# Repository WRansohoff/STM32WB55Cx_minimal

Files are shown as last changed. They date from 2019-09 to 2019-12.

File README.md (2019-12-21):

# STM32WB55 Example Board

**NOTE: I haven't had a chance to test this board much yet, so if you stumble across this, please wait a few weeks before trying to make one!** I'll update the repository with full gerber files and more information once I've checked that the radio/antenna/etc. work. It's my first RF design, so they might not.

I have received a first revision of the boards and verified that the microcontrollers can be programmed with a simple 'blinking LED' application, but I haven't tested any of the advanced peripherals such as USB or Bluetooth. Also, I think that I accidentally reversed the power pins on the USB connector footprint, so it's a good thing that I included a reverse polarity protection diode! That will be fixed shortly, but for now it is a reminder not to order one of these boards yet :)

I've been trying to do a better job of documenting the board designs that I make, so hopefully this can eventually grow into a useful reference design. In the meantime, sorry for the inconvenience and stay tuned.

# Board Renders

I tried to design this so that it could be soldered by hand if you don't have access to PCA services or a reflow station, but the small 0402 parts take a steady hand:

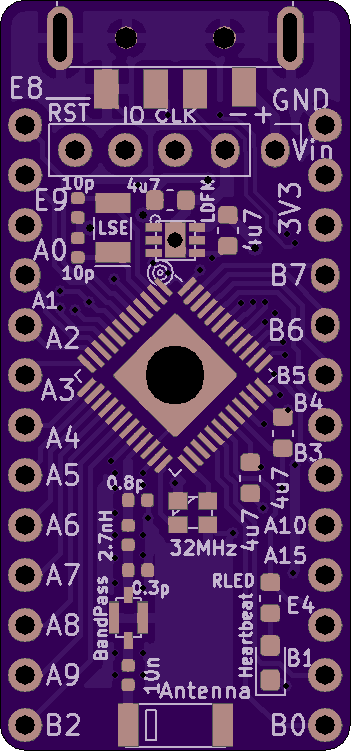
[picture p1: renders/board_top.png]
Board Top

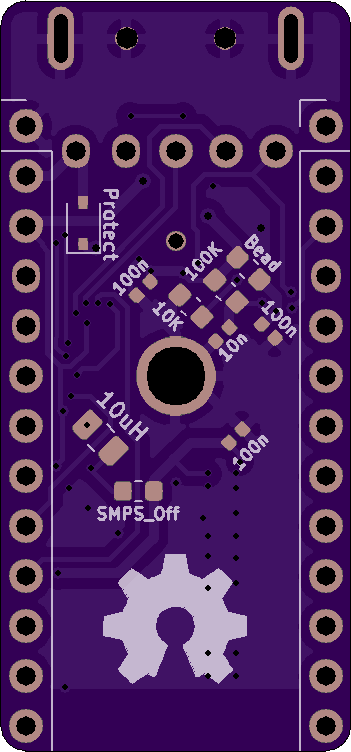
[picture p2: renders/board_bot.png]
Board Bottom


# Future Work

* Obviously, I need to write suitable firmwares to test the radio systems, USB communication, internal switching power supply, etc.

* Instead of using a separate bandpass filter and impedance-matching network, it might be easier to use an integrated filter chip which ST designed for these microcontrollers; part #MLPF-WB55-01E3. It only costs about $0.30, and it seems less error-prone than blindly using the pi filter values from the reference schematics.

* Adding an input button might be a good idea, to extend the range of potential applications.

* I should add a switch or jumper connected to the `BOOT0` pin, because it looks like it is only possible to change or update the co-processor's radio firmware in DFU mode. Fortunately, with the current design, you can remove the 10K resistor on the bottom of the board and solder a jumper between the `BOOT0` side of its pad and the `VDD` side of the 100K resistor which is right next to it. But that's not a good solution.

* Maybe I should move the `SWDIO`, `SWCLK`, and `NRST` pins to the two headers on either side of the board; it's unwieldy to have pin headers overhanging the USB plug.

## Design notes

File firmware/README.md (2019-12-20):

# Test STM32WB55 Firmwares

This directory contains test firmwares for the board design that this repository demonstrates.

I haven't gotten any of the RF stuff working yet, so the only firmware right now is a simple 'blinking LED' program which toggles the on-board LED connected to PE4 to verify that the chip can be programmed, boot, and run an application.

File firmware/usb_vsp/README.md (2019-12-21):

# Overview

Test 'virtual COM port' application, which uses the USB peripheral to set up a virtual serial connection similar to plugging a USB/UART converter into one of the chip's UART peripherals.

I would like to use the example in ST's `STM32Cube` firmware package to test my STM32WB55 USB dongles' 2.4GHz radios, but when I try to use the `BLE_TransparentModeVCP` project with any hardware (including the official 'Nucleo' USB dongle), it fails to enumerate as a USB device on both Windows 10 and Linux machines. It encounters the same error in both cases ('device fails to respond to published address'), and neigher the 'old' nor 'new' style `usbcore` enumerations work on Linux. I started trying to debug the issue and discovered that, at least with STM32 chips, these errors are often caused when a firmware fails to disable the USB peripheral's "VBUS sensing" option. But digging through the endlessly-nesting STM32Cube example code is *way* too tedious and annoying for a fun hobby project. I'm just not going to do it.

I've been meaning to learn about the STM32 USB peripheral anyways though, so I see this as an opportunity rather than a problem. And in fairness to ST, their `BLE_TransparentMode` project for the 'Nucleo' mainboard works very well; the `ST-Link` VCP functionality is excellent. Sadly, the implementation that they use in v1.3 of the STM32WB Cube package does not seem to work, even with their own hardware.

NB: this is a fairly new product line and these sorts of difficulties are not unique to ST, whose products I generally like and admire. It is not unusual or unreasonable to see this sort of "did they even test this?" error, because it is not trivial for a company to test every configuration of every example with every board that they ostensibly support. Plus, as with most other embedded products, you can't expect things to work "out-of-the-box", and you can't expect technical support unless you make large ongoing purchases directly from the company. C'est la vie! `¯\_(ツ)_/¯`

# Current Status

Currently, this test firmware is a non-functional work-in-progress.

I've only started to set up the clocks for the USB peripheral; there is a built-in 48MHz internal RC oscillator, and it looks like you're supposed to use the 'clock recovery system' peripheral to synchronize it with the USB start-of-frame packets which are sent at a 1KHz frequency. I think it's also okay to use a more precise 48MHz signal, such as one derived from an external crystal using the PLL, but the HSI48 oscillator combined with the CRS peripheral looks like the simplest option to start with.

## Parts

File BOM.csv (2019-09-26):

Part ID | Part type | Part size | Part value | Example Digikey Item | Cost (qty: x) | Comment
AE1 | Antenna | Custom | Unictron H2U262GKBA0100 | https://www.digikey.com/short/p2h8zn | $0.64 | Trace antennas are cheaper, but this seemed like a less failure-prone option for a first attempt.
C1 | Capacitor | 0402 | 0.8 pF | https://www.digikey.com/short/p2hrp7 | $0.15 | 50Ω matching filter capacitor. I used the values from ST's evaluation board, figuring they'd probably be fairly close. Ideal values will vary based on your board stackup. Prefer high-quality ceramic capacitors (C0G/NP0)
C2 | Capacitor | 0402 | 0.3 pF | https://www.digikey.com/short/p2hrjw | $0.19 | Another 50Ω matching filter capacitor.
C3, C4, C5 | Capacitor | 0402 | 100 nF | https://www.digikey.com/short/p2hrz2 | $0.30 | Power supply decoupling capacitors. Prefer X5/X7 ceramic capacitors.
C6, C7 | Capacitor | 0603 | 4.7 μF | https://www.digikey.com/short/p2hdqt | $0.34 | SMPS decoupling capacitors for the built-in switching power supply. Prefer X5/X7 ceramic capacitors.
C8, C9 | Capacitor | 0402 | 10 pF | https://www.digikey.com/short/p2hrhj | $0.20 | Filtering capacitors for the 32.768KHz 'Low-Speed External' crystal oscillator. Prefer high-quality C0G/NP0 ceramic capacitors.
C10, C11 | Capacitor | 0603 | 4.7 μF | https://www.digikey.com/short/p2hdqt | $0.34 | Decoupling capacitors for the 3.3V voltage regulator. Prefer X5/X7 ceramic capacitors.
C12 | Capacitor | 0402 | 10 nF | https://www.digikey.com/short/p2hr54 | $0.10 | Filtering capacitor that sits between the 2.45GHz bandpass filter and the antenna. Prefer X7 ceramic capacitor.
C13 | Capacitor | 0402 | 10 nF | https://www.digikey.com/short/p2hr54 | $0.10 | Decoupling capacitor for the reset line.
D1 | Schottky Diode | SOD-323 | 20-40V, 0.5-2A | https://www.digikey.com/short/p2hd37 | $0.31 | Schottky diode to protect against reverse polarity.
D2 | LED | 0603 | Your favorite color | https://www.digikey.com/short/p2hdpf | $0.14 | LED indicator connected to pin E4.
FL1 | Filter | 0805 | 2.45GHz bandpass | https://www.digikey.com/short/p2hndq | $0.24 | Bandpass filter which goes between the 50Ω impedance matching network and the antenna.
J1 | Pins or Sockets | 0.1" | 1x5 | https://www.digikey.com/short/p2hd9v | $0.17 | Programming header; reset, SWDIO, SWCLK, ground, power input. These pin headers are commodities, and it's much chepaer to order them in bulk 1x40 rows.
J2 | USB A Plug | - | - | https://www.digikey.com/short/p2hn02 | $1.30 | USB-A plug, since the chip has a USB peripheral.
J3, J4 | Pins or Sockets | 0.1" | 1x13 | https://www.digikey.com/short/p2hdhn | $0.64 | GPIO pin headers, for plugging into a breadboard or socket.
JP1 | Jumper | 0603 | 0Ω | https://www.digikey.com/short/p2hdnn | $0.10 | Fit a jumper here to disable the internal switching power supply. Requires a corresponding firmware configuration.
L1 | Inductor | 0402 | 2.7 nH | https://www.digikey.com/short/p2hn1q | $0.10 | 50Ω matching filter inductor. Again, the value is from ST's reference design.
L2 | Ferrite Bead | 0603 | - | https://www.digikey.com/short/p2h080 | $0.10 | A ferrite bead to filter out high-frequency noise on the analog voltage pin.
L3 | Inductor | 0805 | 10 μH | https://www.digikey.com/short/p2h03f | $0.14 | Inductor for the internal switching power supply.
R1 | Resistor | 0603 | 10 KΩ | https://www.digikey.com/short/p2hddd | $0.10 | Pull-down resistor for the 'BOOT0' pin.
R2 | Resistor | 0603 | 100 KΩ | https://www.digikey.com/short/p2hd0t | $0.10 | Pull-up resistor for the reset pin. This probably isn't needed since the chips have an internal ~47KΩ pull-up on this pin, but the reference design has a pull-up so I included one.
R3 | Resistor | 0603 | ~1 KΩ | https://www.digikey.com/short/p2hdw9 | $0.10 | Resistor for the LED indicator. Adjust depending on how bright or dim you want the LED to be.
U1 | Microcontroller | QFN-48 | STM32WB55Cx | https://www.digikey.com/short/p2hd4t | $6.65 | Core microcontroller; available with either 512KB or 1MB of Flash memory.
U2 | Voltage Regulator | DFN-6 | LFDM33PVR | https://www.digikey.com/short/p2hdm4 | $0.75 | 500mA low-dropout linear voltage regulator.
Y1 | Crystal | 3.2x1.5mm | 32.768KHz | https://www.digikey.com/short/p2h0zh | $0.41 | Low-Speed External' crystal oscillator.
Y2 | Crystal | 2.0x1.6mm | 32MHz | https://www.digikey.com/short/p2hdhc | $0.64 | High-Speed External' crystal oscillator.
Total: | - | - | - | - | $14.35 | -

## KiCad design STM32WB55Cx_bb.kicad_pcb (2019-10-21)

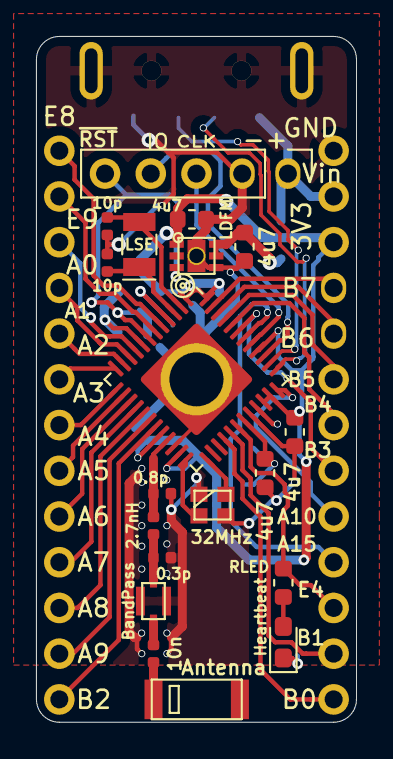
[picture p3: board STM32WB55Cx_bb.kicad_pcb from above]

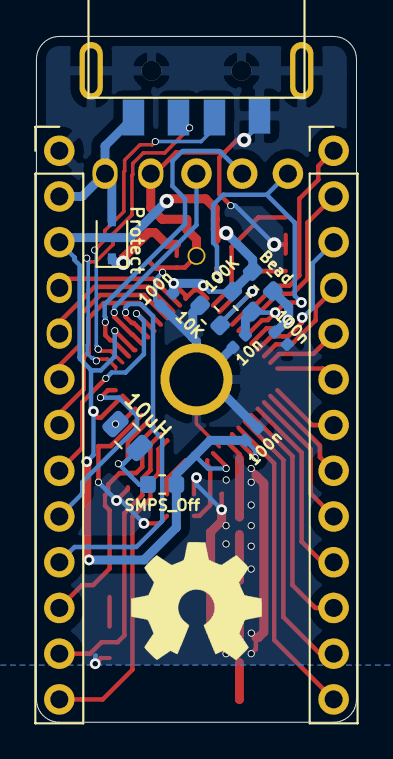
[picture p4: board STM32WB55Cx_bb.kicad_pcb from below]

Board: 2 copper layers, 17.8 x 38.1 mm, 32 parts (13 on the bottom side), 45 nets.

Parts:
AE1: Antenna; AA029_BLE-WiFi_Antenna
C1: 0.8p; C_0402_1005Metric
C2: 0.3p; C_0402_1005Metric
C3, C4, C5: 100n; C_0402_1005Metric
C6, C7, C10, C11: 4u7; C_0603_1608Metric
C8, C9: 10p; C_0402_1005Metric
C12, C13: 10n; C_0402_1005Metric
D1: Protect; D_SOD-323
D2: Heartbeat; LED_0603_1608Metric_Pad1.05x0.95mm_HandSolder
FL1: BandPass; LFB21x_SG_Bandpass
J1: Prog; PinHeader_1x05_P2.54mm_Vertical
J2: USB; USBA_Plug_Molex_480372200
J3: GPIO1; PinHeader_1x13_P2.54mm_Vertical
J4: GPIO2; PinHeader_1x13_P2.54mm_Vertical
JP1: SMPS_Off; R_0603_1608Metric
L1: 2.7nH; L_0402_1005Metric
L2: Bead; R_0603_1608Metric
L3: 10uH; L_0805_2012Metric
R1: 10K; R_0603_1608Metric
R2: 100K; R_0603_1608Metric
R3: RLED; R_0603_1608Metric
U1: STM32WB55Cx; QFN-48-1EP_7x7mm_P0.5mm_EP5.3x5.3mm
U2: LDFM; ST_LDFM_2x2DFN
Y1: LSE; Crystal_SMD_EuroQuartz_EQ161-2Pin_3.2x1.5mm
Y2: 32MHz; NX2016_XTal

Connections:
A0: J3.3, U1.9
A1: J3.4, U1.10
A2: J3.5, U1.11
A3: J3.6, U1.12
A4: J3.7, U1.13
A5: J3.8, U1.14
A6: J3.9, U1.15
A7: J3.10, U1.16
A8: J3.11, U1.17
A9: J3.12, U1.18
A10: J4.9, U1.36
A15: J4.10, U1.42
B0: J4.13, U1.28
B1: J4.12, U1.29
B2: J3.13, U1.19
B3: J4.8, U1.43
B4: J4.7, U1.44
B5: J4.6, U1.45
B6: J4.5, U1.46
B7: J4.4, U1.47
BOOT0: R1.2, U1.4
E4: J4.11, R3.1, U1.30
E8: J3.1, U1.5
E9: J3.2, U1.6
GND: C1.1, C2.1, C3.1, C4.1, C5.2, C6.1, C7.1, C8.2, C9.1, C10.1, C11.1, C13.2, D2.1, FL1.2, FL1.4, J1.2, J2.4, J2.5, J4.1, R1.1, U1.22, U1.32, U1.49, U2.4, U2.7, Y2.2
unnamed: AE1.1, C12.1
unnamed: C2.2, FL1.1, L1.2
unnamed: C3.2, L2.2, U1.8
unnamed: C7.2, JP1.1, L3.2, U1.31
unnamed: C8.1, U1.2, Y1.2
unnamed: C9.2, U1.3, Y1.1
unnamed: C12.2, FL1.3
unnamed: D2.2, R3.2
unnamed: L3.1, U1.33
unnamed: U1.24, Y2.1
unnamed: U1.25, Y2.3
RF1: C1.2, L1.1, U1.21
SWCLK: J1.3, U1.41
SWDIO: J1.4, U1.39
USB_D+: J2.3, U1.38
USB_D-: J2.2, U1.37
VAA: C11.2, D1.1, U2.5, U2.6
VDD: C4.2, C5.1, C6.2, C10.2, J4.3, JP1.2, L2.1, R2.1, U1.1, U1.20, U1.23, U1.34, U1.35, U1.40, U1.48, U2.1
VPP: D1.2, J1.1, J2.1, J4.2
~RST: C13.1, J1.5, R2.2, U1.7, U2.3

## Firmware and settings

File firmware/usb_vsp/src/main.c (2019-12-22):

#include "main.h"

/**
 * Reset handler: copy .data section and clear .bss section
 * before jumping to the main loop.
 */
__attribute__( ( naked ) ) void reset_handler( void ) {
  // Set the stack pointer to the 'end of stack' value.
  __asm__( "LDR r0, =_estack\n\t"
           "MOV sp, r0" );
  // Branch to main.
  __asm__( "B main" );
}

/**
 * Main program.
 */
int main( void ) {
  // Copy initialized data from .sidata (Flash) to .data (RAM)
  memcpy( &_sdata, &_sidata, ( ( void* )&_edata - ( void* )&_sdata ) );
  // Clear the .bss section in RAM.
  memset( &_sbss, 0x00, ( ( void* )&_ebss - ( void* )&_sbss ) );

  // Enable GPIOA/B/C/E, USB, CRS peripherals.
  RCC->AHB2ENR   |= ( RCC_AHB2ENR_GPIOAEN |
                      RCC_AHB2ENR_GPIOBEN |
                      RCC_AHB2ENR_GPIOCEN |
                      RCC_AHB2ENR_GPIOEEN );
  RCC->APB1ENR1  |= ( RCC_APB1ENR1_CRSEN |
                      RCC_APB1ENR1_USBEN );

  // Setup the NVIC hardware interrupts.
  // Use 4 bits for 'priority' and 0 bits for 'subpriority'.
  NVIC_SetPriorityGrouping( 0x00 );

  // Initial clock setup.
  clock_setup();

  // Output type: Push-pull, low-speed.
  PoLED->MODER    &= ~(0x3 << (PiLED * 2));
  PoLED->MODER    |=  (0x1 << (PiLED * 2));
  PoLED->OTYPER   &= ~(0x1 << PiLED);
  PoLED->OSPEEDR  &= ~(0x3 << (PiLED * 2));
  PoLED->OSPEEDR  |=  (0x1 << (PiLED * 2));
  PoLED->ODR      |=  (1 << PiLED);

  // Toggle the LED every second.
  while (1) {
    delay_ms( 1000 );
    PoLED->ODR ^=  (1 << PiLED);
  }
}

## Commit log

2019-09-26 Add library files for the schematic symbols and footprints.
2019-09-26 Add project, schematic, and PCB files.
    [STM32WB55Cx_bb.kicad_pcb, STM32WB55Cx_bb.sch]
2019-09-26 Add board renderings to the readme.
2019-09-26 Add bill of materials CSV file
    [BOM.csv]
2019-09-27 Minor silkscreen changes; make pin numbers more legible, and add an OSHW logo on the bottom.
    [STM32WB55Cx_bb.kicad_pcb]
2019-10-07 Update Readme now that I've had the chance to assemble a board and poke at it a bit.
2019-10-21 Fix the USB plug so that it's pinout is not reversed. And to avoid changing the board design too much, flip the USB plug to the bottom of the board.
    [STM32WB55Cx_bb.kicad_pcb]
2019-12-20 Add makefile, linker script, vector table for the STM32WB55CE chip (48-QFP, 512KB Flash).
2019-12-20 Add core 'blinking LED' application code.
2019-12-21 Add support files for test USB/serial firmware. (The common files like device headers and the linker script should really go one directory up...)
2019-12-21 Add some more detail to the 'current status' readme section.
2019-12-22 Fix USB_VSP project memcpy/memset calls.
    [main.c]
2019-12-23 Clear power-down bit before performing an internal peripheral reset, as recommended by the reference manual.
